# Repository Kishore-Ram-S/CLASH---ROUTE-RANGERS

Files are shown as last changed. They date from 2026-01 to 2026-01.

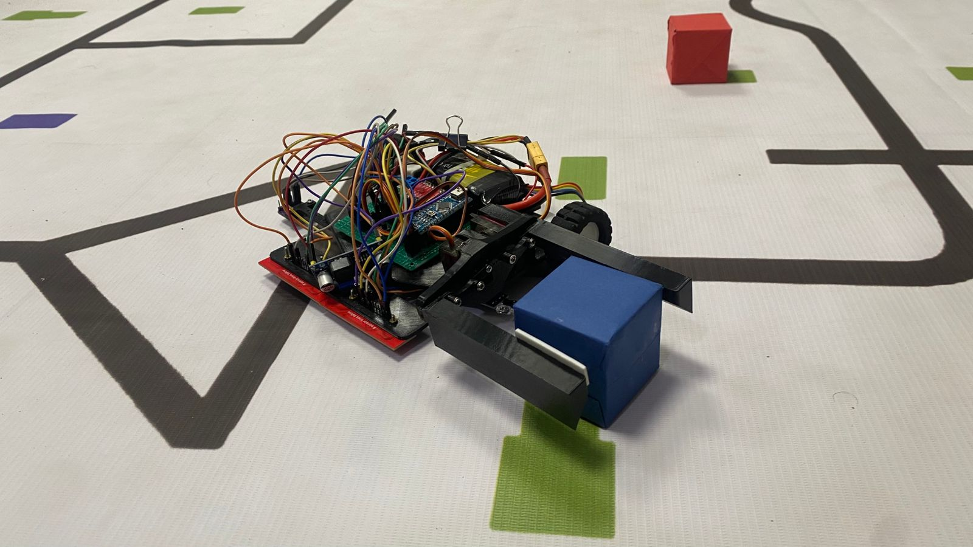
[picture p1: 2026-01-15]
Pic-of-bot-only.png

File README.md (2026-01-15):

# CLASH Search & Rescue Bot (Route Rangers) 🤖🏆





An **autonomous line follower + color-based pick & place rescue bot** built for the **CLASH event (Build Club SSN)**.  
The robot follows the line using QTR sensors, detects a box using an IR sensor, identifies the box color using the **TCS34725**, and picks it using our **custom PLA 3D-printed gripper**.

---

## 🚀 Features
- **Autonomous line following** using **2× QTR sensors**
- **Phase 1 Scan → Broken line detection → Mandatory U-Turn**
- **Instant box detection** using IR sensor (stops immediately)
- **Color recognition** using **TCS34725 RGB sensor**
- **Pick & Place** using **custom 3D-printed PLA gripper**
- **Smooth DC motor control** using **TB6612FNG**
- **Bluetooth support** using **HC-05** (debug/control)

---

## 🧠 Working Logic (Competition Flow)
1. **Scan Run (Phase 1):** Bot follows the track and ignores boxes until the broken-line scan point.
2. **Mandatory U-Turn:** After scan completion, the bot performs a **180° turn**.
3. **Search & Rescue (Phase 2):** Bot hunts for boxes, detects them using IR, scans color using TCS34725, and performs **instant grab**.
4. **Delivery:** Bot navigates to intersection and turns based on held box color:
   - **RED → Left Zone**
   - **BLUE → Right Zone**
   - **GREEN → Avoid (no pickup)**

---

## 🛠 Hardware Components

| Component | Qty | Description |
|---|-----|---|
| **Arduino Nano** | 1 | Main microcontroller |
| **QTR IR Sensors** | 2 | Line detection sensors |
| **TCS34725 Color Sensor** | 1 | RGB color detection |
| **IR Sensor** | 1 | Box/object detection |
| **TB6612FNG Motor Driver** | 1 | Dual H-bridge driver |
| **N20 Motors** | 2 | Drive motors |
| **N20 Wheels** | 2 | Wheels for locomotion |
| **HC-05 Bluetooth Module** | 1 | Wireless communication |
| **Custom PLA Gripper** | 1 | 3D-printed gripper (designed by us) |

---

## ⚙️ Code Highlights
- **State Machine based navigation**
  - `NAV_TO_SCAN → SCAN_UTURN → HUNTING → DELIVERING → DROP_OFF`
- **PID line following** for stable tracking
- **Gap chain counting** for broken-line scan detection
- **Instant stop + scan + grab** mechanism for quick pickup

---

## 📚 Libraries Required
- **QTRSensors**
- **SparkFun TB6612FNG Motor Driver**
- **Adafruit TCS34725**
- **Servo**
- **Wire**

---

## 📌 Notes
- Servo angles and thresholds are tuned for our build (may need calibration for other setups).
- IR sensor output logic may vary depending on module type.

---

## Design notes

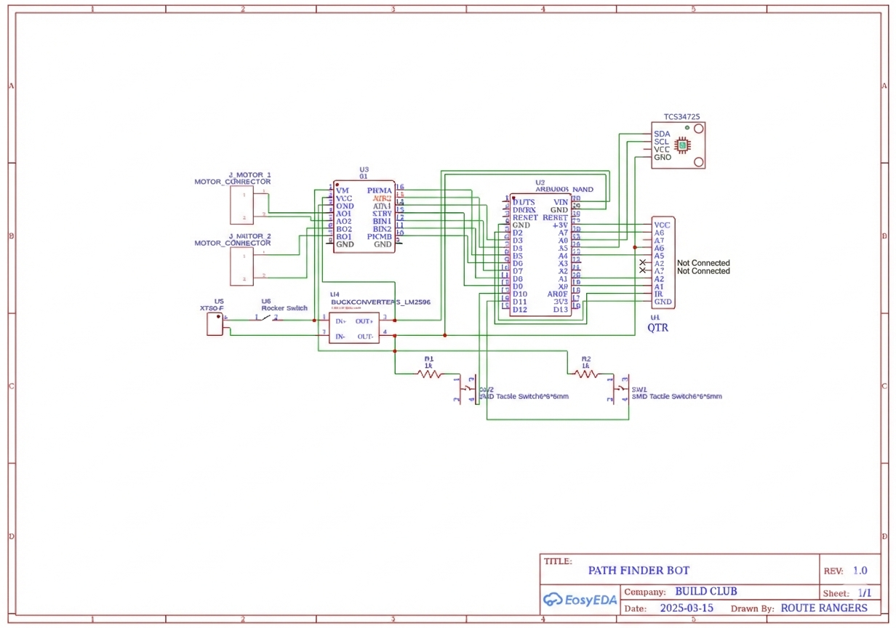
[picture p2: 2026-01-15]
Clash_Pin_Connections.png

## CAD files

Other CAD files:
claw_clash.f3d

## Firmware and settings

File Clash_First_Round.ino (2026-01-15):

//CLASH PHASE_1 FINAL

#include <QTRSensors.h>
#include <SparkFun_TB6612.h>
#include <Wire.h>
#include "Adafruit_TCS34725.h"
#include <Servo.h>

Servo servo_lift;
Servo servo_grip;

// --- COLOR SENSOR ---
Adafruit_TCS34725 tcs = Adafruit_TCS34725(TCS34725_INTEGRATIONTIME_614MS, TCS34725_GAIN_60X);

char data;
int pos_lift = 0;
int pos_grip = 0;

// QTR Sensor
QTRSensors qtr;
const uint8_t SensorCount = 6;
uint16_t sensorValues[SensorCount];

// PID
float Kp = 0.09;
float Ki = 0.0001;  
float Kd = 0.33;
int P, I, D, lastError = 0;

// --- MOTOR SETTINGS ---
int TURN_SPEED = 50; 
int TURN_SPEEDr = -50;
int TURN_ALIGN_DELAY = 300; 

// *** NEW: POST-TURN REVERSE SETTINGS ***
// Time to drive backward after a hard turn to catch the strip
const int REVERSE_AFTER_TURN_MS = 350; 
const int REVERSE_SPEED = 50; // Safe speed for reversing

// Timers
const int IR_TURN_IGNORE = 0;   
const int TURN_COOLDOWN_TIME = 1500;
const int STARTUP_GRACE_PERIOD = 0; 

const int BLACK_THRESHOLD = 700;

// SPEED
uint8_t maxspeeda = 90;
uint8_t maxspeedb = 90;
uint8_t basespeeda = 40;
uint8_t basespeedb = 40;

// Color Counting & Mission Flags
int countRed = 0;
int countGreen = 0;
int countBlue = 0;
boolean ir = false; 

boolean all_black = false;       
boolean printedAllBlack = false; 
boolean boxLifted = false;       

// Memory
unsigned long lastTurnTime = 0;
unsigned long missionStartTime = 0;

// Pins
#define AIN1 3
#define BIN1 7
#define AIN2 4
#define BIN2 8
#define PWMA 5
#define PWMB 6
#define STBY 9

int buttoncalibrate = 13;
int ir_pin = 12;

const int offsetA = 1;
const int offsetB = 1;
Motor motor1 = Motor(AIN1, AIN2, PWMA, offsetA, STBY);
Motor motor2 = Motor(BIN1, BIN2, PWMB, offsetB, STBY);

// Ramp
uint8_t currentSpeedA = 0;
uint8_t currentSpeedB = 0;
const uint8_t rampStep = 5;
const uint16_t rampDelay = 15;
unsigned long lastRampTime = 0;

boolean onoff = false;
unsigned long lastWhiteTime = 0;
const unsigned long WHITE_TIMEOUT = 50;

void setup() 
{
    qtr.setTypeAnalog();
    qtr.setSensorPins((const uint8_t[]){A0,A1,A2,A3,A6,A7}, SensorCount);

    Serial.begin(9600);
    Serial.println("--- SYSTEM BOOTING ---");

    if (tcs.begin()) {
        Serial.println("Color Sensor Found.");
    } else {
        Serial.println("ERROR: No TCS34725 found");
    }

    delay(500);

    pinMode(LED_BUILTIN, OUTPUT);
    pinMode(buttoncalibrate, INPUT);
    pinMode(ir_pin, INPUT); 

    servo_lift.attach(10);
    servo_grip.attach(11);

    servo_lift.write(160);
    servo_grip.write(90);

    boolean Ok = false;
    Serial.println("Waiting for Calibration...");

    while (!Ok) 
    {
        if (digitalRead(buttoncalibrate) == HIGH) 
        {
            delay(1000);
            calibration();
            Ok = true;
        }
    }

    brake(motor1, motor2);
    Serial.println("Ready. Send 'S' to start.");
}

void calibration() 
{
    digitalWrite(LED_BUILTIN, HIGH);
    Serial.println("CALIBRATING (360 SPIN)...");
    for (uint16_t i = 0; i < 200; i++) 
    {
        motor1.drive(30);   
        motor2.drive(-30);  
        qtr.calibrate();    
        delay(20);
    }
    brake(motor1, motor2);
    digitalWrite(LED_BUILTIN, LOW);
    Serial.println("Calibration Done.");
}

void loop() 
{
    if (Serial.available()) 
    {
        data = Serial.read();

        if (data == 'i') Kp += 0.005;
        else if (data == 'd') Kp -= 0.005;
        else if (data == 'j') Ki += 0.00005;
        else if (data == 'e') Ki -= 0.00005;
        else if (data == 'k') Kd += 0.01;
        else if (data == 'f') Kd -= 0.01;
        else if (data == 'l') { maxspeeda += 25; maxspeedb += 25; basespeeda += 25; basespeedb += 25; } 
        else if (data == 'g') { maxspeeda -= 25; maxspeedb -= 25; basespeeda -= 25; basespeedb -= 25; } 
        else if (data == 's') { 
            onoff = false; P = I = D = 0; 
            all_black = false; printedAllBlack = false; boxLifted = false; 
            countRed = 0; countGreen = 0; countBlue = 0; 
            Serial.println("STOPPED (Mission Reset).");
        } 
        else if (data == 'S') { 
            onoff = true; currentSpeedA = 0; currentSpeedB = 0; lastRampTime = millis(); 
            missionStartTime = millis(); 
            Serial.println("STARTED.");
        } 
        else if (data == 't') TURN_SPEED += 10;
        else if (data == 'T') TURN_SPEED -= 10;
    }

    if (digitalRead(buttoncalibrate) == HIGH) 
    {
        onoff = !onoff;
        delay(500);
        if (onoff) { 
            currentSpeedA = 0; currentSpeedB = 0; lastRampTime = millis(); 
            missionStartTime = millis(); 
            Serial.println("Button Start.");
        }
    }

    if (onoff) 
    {
        if (millis() - lastRampTime >= rampDelay) 
        {
            lastRampTime = millis();
            if (currentSpeedA < basespeeda) currentSpeedA += rampStep;
            if (currentSpeedB < basespeedb) currentSpeedB += rampStep;
        }

        PID_control(currentSpeedA, currentSpeedB);
    } 
    else 
    {
        brake(motor1, motor2);
    }
}

// --- HELPER FUNCTIONS ---

String getColorName(int c) {
    if (c == 0) return "RED";
    if (c == 1) return "GREEN";
    if (c == 2) return "BLUE";
    return "UNKNOWN";
}

int getColor() {
  uint16_t r, g, b, c;
  tcs.getRawData(&r, &g, &b, &c);
  if (c < 100) return 3; 
  if (r > g && r > b) return 0;
  else if (g > r && g > b) return 1;
  else if (b > r && b > g) return 2;
  else return 3;
}

void forward_brake(int posa, int posb) { motor1.drive(posa); motor2.drive(posb); }

int max_1(int &r, int &g, int &b) {
    if (r > g && r > b) return 0;
    else if (g > r && g > b) return 1;
    else if (b > r && b > g) return 2;
    return 0; 
}

void lift() {
    Serial.println("ACTION: Lifting Box...");
    for (pos_lift = 160; pos_lift >= 55; pos_lift -= 1) { servo_lift.write(pos_lift); delay(15); }
    for (pos_grip = 90; pos_grip >= 28; pos_grip -= 1) { servo_grip.write(pos_grip); delay(15); }
    for (pos_lift = 55; pos_lift <= 160; pos_lift += 1) { servo_lift.write(pos_lift); delay(15); }
    
    boxLifted = true; 
    Serial.println(">> BOX SECURED. Heading to Drop Zone.");
}

void drop() {
    Serial.println("ACTION: Dropping Box...");
    for (pos_lift = 160; pos_lift >= 55; pos_lift -= 1) { servo_lift.write(pos_lift); delay(15); }
    for (pos_grip = 28; pos_grip <= 90; pos_grip += 1) { servo_grip.write(pos_grip); delay(15); }
    for (pos_lift = 55; pos_lift <= 160; pos_lift += 1) { servo_lift.write(pos_lift); delay(15); }
    Serial.println(">> MISSION COMPLETE.");
}

// --- HARD TURN FUNCTIONS WITH REVERSE ---
void turnLeftBlocking() {
    Serial.println(">> DETECTED LEFT... Aligning...");
    
    // 1. Kick forward
    motor1.drive(40); motor2.drive(40);
    delay(TURN_ALIGN_DELAY); 

    // 2. Safety Check (Crossing)
    qtr.readLineBlack(sensorValues);
    if (sensorValues[5] > BLACK_THRESHOLD) {
        Serial.println(">> CROSSING DETECTED (Abort Turn)");
        motor1.drive(40); motor2.drive(40);
        delay(200);
        return; 
    }

    // 3. Spin
    motor1.drive(-TURN_SPEED); motor2.drive(TURN_SPEED);
    delay(200); 
    
    // 4. Catch Line
    while(1) {
        qtr.readLineBlack(sensorValues);
        if (sensorValues[1] > BLACK_THRESHOLD || sensorValues[2] > BLACK_THRESHOLD || 
            sensorValues[3] > BLACK_THRESHOLD || sensorValues[4] > BLACK_THRESHOLD) {
            break;
        }
    }

    // 5. Active Brake
    motor1.drive(50); motor2.drive(-50); 
    delay(50);
    brake(motor1, motor2);
    delay(200); // Fully stop before reversing

    // 6. *** REVERSE ALIGNMENT ***
    Serial.println(">> REVERSING to Catch Strip...");
    motor1.drive(-REVERSE_SPEED); 
    motor2.drive(-REVERSE_SPEED/2);
    delay(REVERSE_AFTER_TURN_MS); 
    
    brake(motor1, motor2);
    delay(100);

    Serial.println(">> TURN COMPLETE. Resuming PID.");
    lastTurnTime = millis(); 
}

void turnRightBlocking() {
    Serial.println(">> DETECTED RIGHT... Aligning...");
    
    // 1. Kick forward
    motor1.drive(40); motor2.drive(40);
    delay(TURN_ALIGN_DELAY); 

    // 2. Safety Check (Crossing)
    qtr.readLineBlack(sensorValues);
    if (sensorValues[0] > BLACK_THRESHOLD) {
        Serial.println(">> CROSSING DETECTED (Abort Turn)");
        motor1.drive(40); motor2.drive(40);
        delay(200);
        return; 
    }

    // 3. Spin
    motor1.drive(TURN_SPEED); motor2.drive(-TURN_SPEED);
    delay(200); 
    
    // 4. Catch Line
    while(1) {
        qtr.readLineBlack(sensorValues);
        if (sensorValues[1] > BLACK_THRESHOLD || sensorValues[2] > BLACK_THRESHOLD || 
            sensorValues[3] > BLACK_THRESHOLD || sensorValues[4] > BLACK_THRESHOLD) {
            break;
        }
    }

    // 5. Active Brake
    motor1.drive(-50); motor2.drive(50); 
    delay(50);
    brake(motor1, motor2);
    delay(200);

    // 6. *** REVERSE ALIGNMENT ***
    Serial.println(">> REVERSING to Catch Strip...");
    motor1.drive(-REVERSE_SPEED/2); 
    motor2.drive(-REVERSE_SPEED);
    delay(REVERSE_AFTER_TURN_MS); 
    
    brake(motor1, motor2);
    delay(100);

    Serial.println(">> TURN COMPLETE. Resuming PID.");
    lastTurnTime = millis(); 
}

void before_all_black () {
    // STARTUP SAFETY
    if (millis() - missionStartTime < STARTUP_GRACE_PERIOD) return;
    
    // IR IGNORE removed (Detects immediately after reverse)

    if (digitalRead(ir_pin) == 0 && ir==false) { 
        brake(motor1,motor2);
        delay(1000); 
        ir=true; 
        int color = getColor(); 
        if (color == 0) countRed++;
        else if (color == 1) countGreen++;
        else if (color == 2) countBlue++;
        
        Serial.print("Detected: "); Serial.println(getColorName(color));
        Serial.print("R:"); Serial.print(countRed); Serial.print(" G:"); Serial.print(countGreen); Serial.print(" B:"); Serial.println(countBlue);
    }
    else if (digitalRead(ir_pin) == 1 && ir==true) {
        ir = false;
    }
}

void after_all_black () {
    if (boxLifted) {
         // Drive forward until All Black is detected
        while (true) {
            motor1.drive(60);  // Adjust speed if needed (stable speed)
            motor2.drive(60); 

            qtr.readLineBlack(sensorValues); // Read sensors

            // Check if ALL sensors are seeing black
            bool allSensorsBlack = true;
            for (uint8_t i = 0; i < SensorCount; i++) {
                if (sensorValues[i] < BLACK_THRESHOLD) {
                    allSensorsBlack = false;
                    break;
                }
            }

            // If all are black, Stop and Exit this loop
            if (allSensorsBlack) {
                brake(motor1, motor2);
                delay(100); // Small pause to stabilize
                break;
            }
        }
            
    }
    if (millis() - missionStartTime < STARTUP_GRACE_PERIOD) return;

    if (digitalRead(ir_pin) == 0 && ir==false) { 
        brake(motor1,motor2);
        delay(1000); 
        ir=true; 
        int color = getColor();
        int maximum = max_1(countRed,countGreen,countBlue);
        if (color == maximum) {
            Serial.println(">>> MATCH! <<<");
            lift();
        } else {
            Serial.println(">>> NO MATCH. Ignoring. <<<");
        }
        delay(1000); 
    }
    else if (digitalRead(ir_pin) == 1) {
        ir = false;
    }
}

void PID_control(uint8_t baseA, uint8_t baseB) 
{
    uint16_t position = qtr.readLineBlack(sensorValues);

    // *** NEW: DROP LOGIC ***
    // Checks if the box is lifted and we see the Final All-Black Line
    if (boxLifted && (millis() - lastTurnTime > TURN_COOLDOWN_TIME)) 
    {
        bool isDropZone = true;
        for (uint8_t i = 0; i < SensorCount; i++) {
            if (sensorValues[i] <= BLACK_THRESHOLD) {
                isDropZone = false;
                break;
            }
        }

        if (isDropZone) {
            Serial.println("!!! DROP ZONE DETECTED !!!");
            brake(motor1, motor2);
            delay(500);
            drop();
            onoff = false; P = I = D = 0; 
            all_black = false; printedAllBlack = false; boxLifted = false; 
            countRed = 0; countGreen = 0; countBlue = 0; 
            Serial.println("STOPPED (Mission Reset).");
        }
    }
    // ************************

    // --- CHECK FOR HARD TURNS ---
    if (millis() - lastTurnTime > TURN_COOLDOWN_TIME) {
        
        bool extremeLeft = (sensorValues[0] > BLACK_THRESHOLD);
        bool extremeRight = (sensorValues[5] > BLACK_THRESHOLD);

        if (extremeLeft && extremeRight) {
             // Crossing Protection
             Serial.println(">> CROSSING: Forcing Straight");
             position = 2500; 
             lastTurnTime = millis(); 
        }
        else if (extremeLeft) {
            turnLeftBlocking();
            lastError = 0; 
            return; 
        }
        else if (extremeRight) {
            turnRightBlocking();
            lastError = 0;
            return; 
        }
    }

    // --- CHECK FOR ALL BLACK (First Pass / Hunting Mode Switch) ---
    if ((!all_black) && (millis() - lastTurnTime > 750)) {
        bool tempAllBlack = true;
        for (uint8_t i = 0; i < SensorCount; i++) {
            if (sensorValues[i] <= BLACK_THRESHOLD) {
                tempAllBlack = false;
                break;
            }
        }
        if (tempAllBlack) {
            all_black = true; 
            Serial.println("!!! FIRST ALL BLACK PASSED -> HUNTING MODE !!!");
        }
    }

    // --- PID CALCULATION ---
    int error = position - 2500;
    P = error;
    I += error;
    D = error - lastError;
    lastError = error;

    int motorspeed = P * Kp + I * Ki + D * Kd;
    int motorspeeda = baseA + motorspeed;
    int motorspeedb = baseB - motorspeed;

    motorspeeda = constrain(motorspeeda, 0, maxspeeda);
    motorspeedb = constrain(motorspeedb, 0, maxspeedb);
    
    // --- WHITE GAP CHECK ---
    bool allWhite = true;
    for (uint8_t i = 0; i < SensorCount; i++) {
        if (sensorValues[i] > BLACK_THRESHOLD) allWhite = false;
    }

    if (allWhite) {
        forward_brake(baseA, baseB);
    } 
    else {
        forward_brake(motorspeeda, motorspeedb);
    }

    // --- MODE EXECUTION ---
    if (!all_black) {
        before_all_black(); 
    }
    else {
        after_all_black(); 
    }
}

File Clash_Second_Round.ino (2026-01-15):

// CLASH PHASE 2


#include <QTRSensors.h>
#include <SparkFun_TB6612.h>
#include <Wire.h>
#include "Adafruit_TCS34725.h"
#include <Servo.h>

// --- COMPONENT OBJECTS ---
Servo servo_lift;
Servo servo_grip;
Adafruit_TCS34725 tcs = Adafruit_TCS34725(TCS34725_INTEGRATIONTIME_50MS, TCS34725_GAIN_1X);
QTRSensors qtr;

// --- PIN DEFINITIONS ---
#define AIN1 3
#define BIN1 7
#define AIN2 4
#define BIN2 8
#define PWMA 5
#define PWMB 6
#define STBY 9

#define PIN_CALIBRATE 13
#define PIN_IR 12        
#define PIN_SERVO_LIFT 10
#define PIN_SERVO_GRIP 11

// --- MOTOR SETUP ---
const int offsetA = 1;
const int offsetB = 1;
Motor motor1 = Motor(AIN1, AIN2, PWMA, offsetA, STBY);
Motor motor2 = Motor(BIN1, BIN2, PWMB, offsetB, STBY);

// --- PID CONSTANTS ---
float Kp = 0.09;
float Ki = 0.0002; 
float Kd = 0.45; 
int P, I, D, lastError = 0;

// --- SPEED SETTINGS ---
const uint8_t MAX_SPEED = 100;
const uint8_t BASE_SPEED = 50;
const uint8_t TURN_SPEED = 70;

// --- SERVO VARIABLES ---
int pos_lift = 0;
int pos_grip = 0;
bool boxLifted = false;

// --- BOX COUNTERS ---
int redCount = 3;
int blueCount = 3;
int greenCount = 1;

// --- STATE MACHINE ---
enum MissionState {
  IDLE,
  NAV_TO_SCAN,      // Phase 1: Blind Driving
  SCAN_UTURN,       // Transition: The 180 Spin
  HUNTING,          // Phase 2: Active Search & Rescue
  AVOIDING,         
  DELIVERING,       
  DROP_OFF,         
  PARK              
};

MissionState currentState = IDLE;
int heldBoxColor = -1; // 0=Red, 1=Green, 2=Blue

// --- SENSOR VARIABLES ---
const uint8_t SensorCount = 6;
uint16_t sensorValues[SensorCount];
const int BLACK_THRESH = 600;    

// --- GAP CHAIN VARIABLES ---
bool wasOnLine = true;        
int gapCount = 0;             
unsigned long lastGapTime = 0;
const unsigned long GAP_CHAIN_TIMEOUT = 2000; 
const int BROKEN_LINE_THRESHOLD = 3; 

// --- TURN COOLDOWN ---
unsigned long lastTurnTime = 0;

// --- FUNCTION PROTOTYPES ---
void stopRobot(); 
void runPID_WithGapCounting();
void runPID_Normal();
void checkObject();
int getPreciseColor();
void performUTurn();
void nudgeAround();
void checkIntersectionForDelivery();
void turnLeft();
void turnRight();
void lift(); 
void drop(); 
void resetServos();

void setup() {
  Serial.begin(9600);
  
  // 1. Hardware Init
  qtr.setTypeAnalog();
  qtr.setSensorPins((const uint8_t[]){A7, A6, A3, A2, A1, A0}, SensorCount);

  pinMode(PIN_CALIBRATE, INPUT);
  pinMode(PIN_IR, INPUT);
  pinMode(LED_BUILTIN, OUTPUT);

  servo_lift.attach(PIN_SERVO_LIFT);
  servo_grip.attach(PIN_SERVO_GRIP);
  resetServos(); 

  // 2. Color Sensor Init
  if (tcs.begin()) {
    Serial.println("TCS34725 Found.");
    tcs.setInterrupt(false); 
  } else {
    Serial.println("ERR: No Color Sensor");
    while(1); 
  }

  // 3. Calibration
  Serial.println("Waiting for Calibration (Press Button)...");
  while (digitalRead(PIN_CALIBRATE) == LOW) {} 
  
  digitalWrite(LED_BUILTIN, HIGH);
  Serial.println("Calibrating...");
  for (int i = 0; i < 250; i++) {
    qtr.calibrate();
    if(i < 60 || i > 180) { motor1.drive(40); motor2.drive(-40); }
    else { motor1.drive(-40); motor2.drive(40); }
    delay(20);
  }
  stopRobot();
  digitalWrite(LED_BUILTIN, LOW);
  Serial.println("Ready. Press to Start.");
  
  while (digitalRead(PIN_CALIBRATE) == LOW) {} 
  delay(1000);
  
  // Start Mission
  currentState = NAV_TO_SCAN;
  gapCount = 0; 
}

void loop() {
  switch (currentState) {
    case IDLE:
      stopRobot();
      break;

    case NAV_TO_SCAN:
      // --- PHASE 1: IGNORE BOXES ---
      runPID_WithGapCounting(); 
      
      // Check for Broken Lines (End of Scan)
      if (gapCount >= BROKEN_LINE_THRESHOLD) {
         Serial.println("Phase 1 Complete.");
         motor1.drive(BASE_SPEED); motor2.drive(BASE_SPEED);
         delay(400); 
         stopRobot();
         currentState = SCAN_UTURN;
      }
      break;

    case SCAN_UTURN:
      performUTurn(); 
      currentState = HUNTING;
      break;

    case HUNTING:
      // --- PHASE 2: SEARCH & RESCUE ---
      runPID_Normal(); 
      checkObject(); 
      break;

    case AVOIDING:
      nudgeAround();
      currentState = HUNTING;
      break;

    case DELIVERING:
      runPID_Normal();
      checkIntersectionForDelivery();
      break;

    case DROP_OFF:
      drop(); 
      Serial.println("Resuming Hunt.");
      performUTurn(); 
      currentState = HUNTING; 
      break;

    case PARK:
      stopRobot();
      Serial.println("MISSION COMPLETE");
      while(1); 
      break;
  }
}

// =============================================================
// LOGIC FUNCTIONS
// =============================================================

// --- PID PHASE 1 ---
void runPID_WithGapCounting() {
  uint16_t position = qtr.readLineBlack(sensorValues);
  bool currentlyOnLine = false;
  for(int i=0; i<SensorCount; i++) {
    if(sensorValues[i] > BLACK_THRESH) currentlyOnLine = true;
  }

  // GAP COUNTING
  if (!wasOnLine && currentlyOnLine) {
    unsigned long timeBetweenGaps = millis() - lastGapTime;
    if (timeBetweenGaps > GAP_CHAIN_TIMEOUT) {
       gapCount = 1; 
       Serial.println("Gap Chain Reset");
    } else {
       gapCount++; 
       Serial.print("Gap: "); Serial.println(gapCount);
    }
    lastGapTime = millis(); 
  }
  wasOnLine = currentlyOnLine; 

  // MOVE
  if (!currentlyOnLine) {
    motor1.drive(BASE_SPEED); motor2.drive(BASE_SPEED);
    return; 
  }
  int error = position - 2500;
  P = error; I += error; D = error - lastError; lastError = error;
  I = constrain(I, -1000, 1000);
  int motorSpeed = P * Kp + I * Ki + D * Kd;
  int speedA = constrain(BASE_SPEED + motorSpeed, 0, MAX_SPEED);
  int speedB = constrain(BASE_SPEED - motorSpeed, 0, MAX_SPEED);
  motor1.drive(speedA); motor2.drive(speedB);
}

// --- PID PHASE 2 ---
void runPID_Normal() {
  uint16_t position = qtr.readLineBlack(sensorValues);
  int error = position - 2500;
  P = error; I += error; D = error - lastError; lastError = error;
  I = constrain(I, -1000, 1000);
  int motorSpeed = P * Kp + I * Ki + D * Kd;
  int speedA = constrain(BASE_SPEED + motorSpeed, 0, MAX_SPEED);
  int speedB = constrain(BASE_SPEED - motorSpeed, 0, MAX_SPEED);
  motor1.drive(speedA); motor2.drive(speedB);
}
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
